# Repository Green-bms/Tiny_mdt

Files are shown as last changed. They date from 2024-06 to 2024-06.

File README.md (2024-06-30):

# Tiny_mdt
A useful tiny gadget! <br>  
Youtube video: https://www.youtube.com/embed/fY5Y1o6QoCc?si=GF92eTSO-mVCjJeZ <br> 
<br> 
Tiny mdt is a small electronic gadget that measures environmental data and shows it on a small 0.96" OLED display. 
The data is acquired and processed by an ATtiny85 microcontroller.<br> 
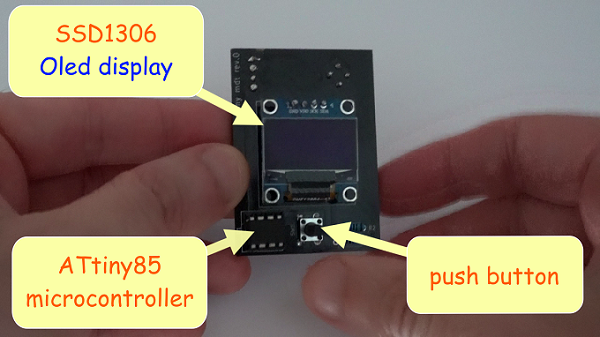
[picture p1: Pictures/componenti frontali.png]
) <br> 
The device is powered by a 3v CR2032 coin cell
the card only works when the power button is pressed and turns off when released.
So most of the time the device stays off, saving energy.
According to my calculations, with moderate use, the battery should last about 10-12 months.
I created the software with Arduino IDE. The big challenge was to find the lightest libraries to fit in the limited memory of the ATtiny85.
The project is available in 2 versions, with the same PCB (only the sensors to be used and the software to be loaded into the microcontroller change) <br>
## Type 1: htt
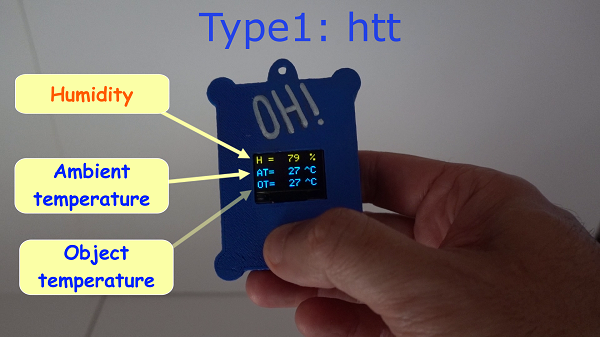
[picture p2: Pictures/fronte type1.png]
) <br> 
This variant uses the HTU21D sensor which measures humidity and ambient temperature.
Furthermore, the temperature of an object is also detected using the MLX90614 infrared thermometer. <br> 
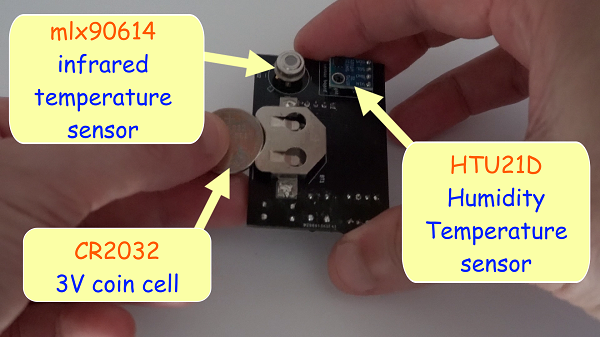
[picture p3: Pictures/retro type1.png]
) <br>
## Type 2: htp
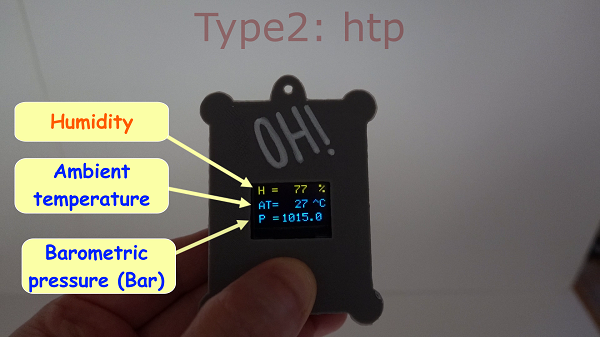
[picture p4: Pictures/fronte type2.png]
) <br> 
This is a small portable weather station in the palm of your hand!
The board uses the excellent BME280 sensor which measures humidity, temperature and barometric pressure.<br> 
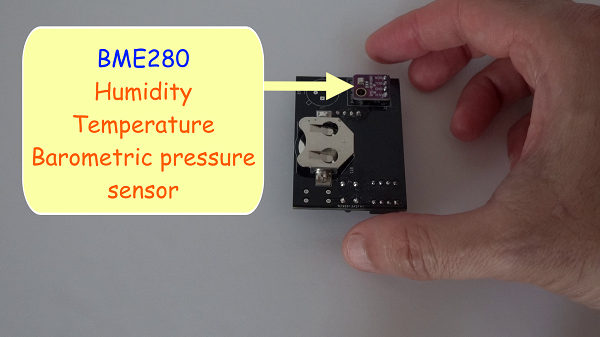
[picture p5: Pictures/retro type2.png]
) <br>
## Do it yourself
This project is completely open source and is very simple to create. <br>
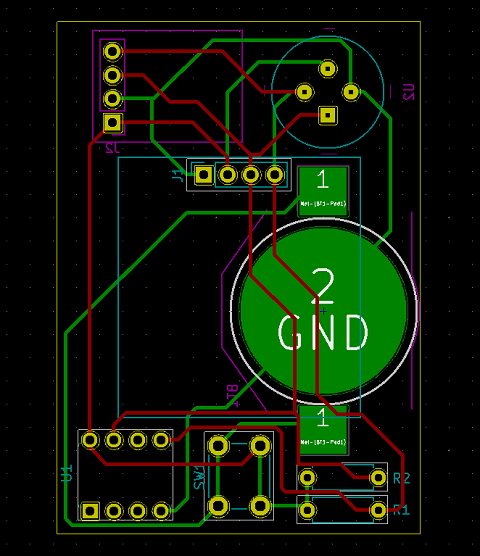
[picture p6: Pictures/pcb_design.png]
) <br>
I deliberately used tht components to facilitate soldering.<br>
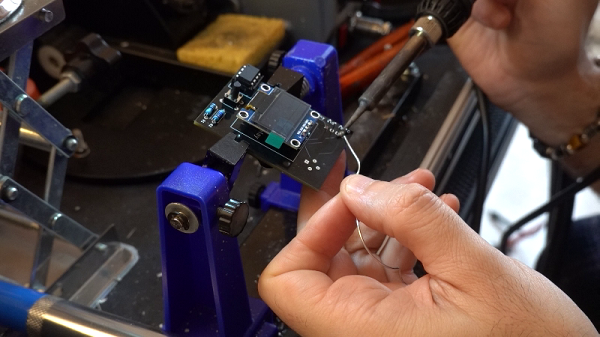
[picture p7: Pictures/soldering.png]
) <br>
The ATtiny85 microcontroller is socket mounted, so it can be easily removed and programmed using the maker's favorite programmer.
For example, I used the "Wemos as ISP" programmer that you find here: https://github.com/Green-bms/Wemos-as-ISP <br>
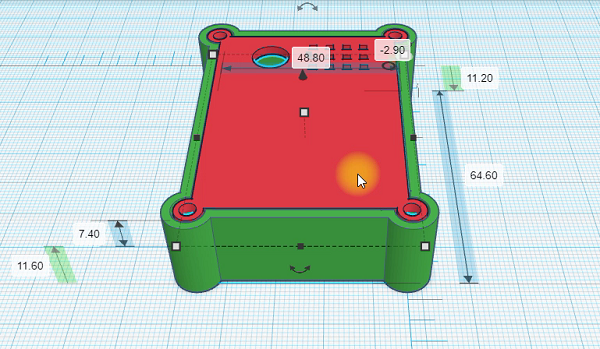
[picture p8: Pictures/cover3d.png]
) <br>

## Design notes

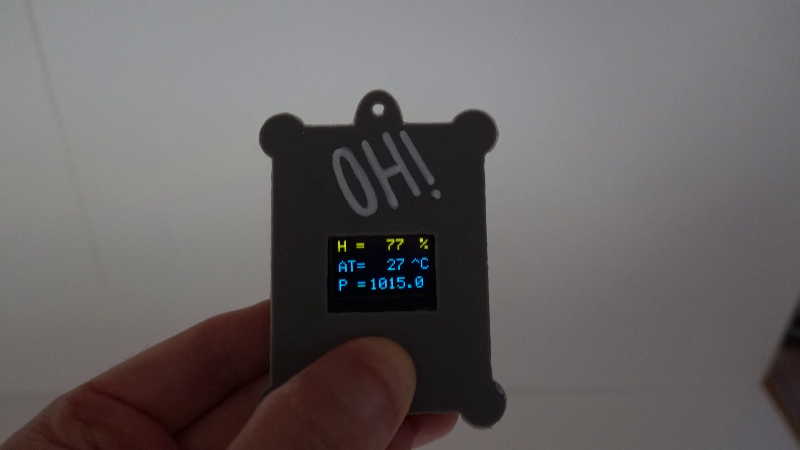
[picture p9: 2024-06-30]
Pictures/Istantanea.png

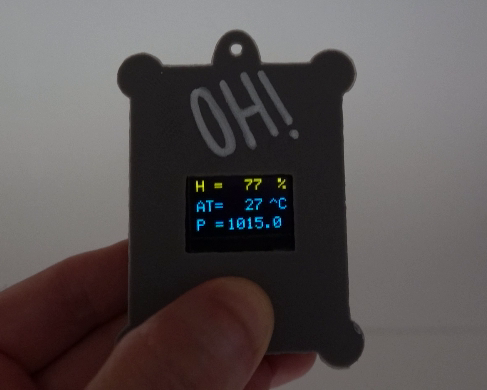
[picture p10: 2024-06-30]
Pictures/copertina.png

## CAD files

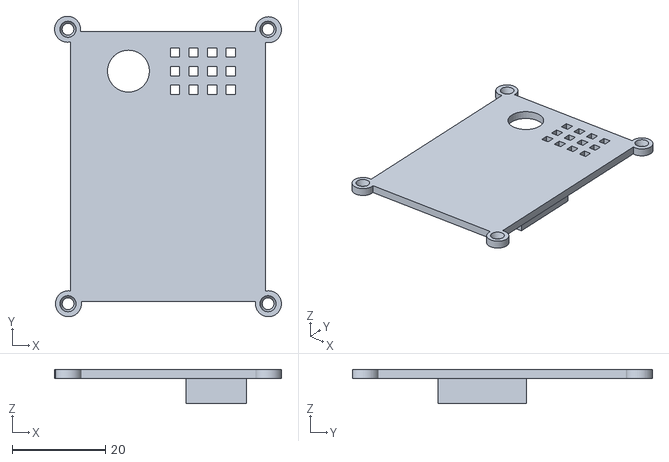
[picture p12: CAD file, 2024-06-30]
Cover 3D/Tiny_mdt_cover_htt_2.stl
48.8 x 64.6 x 7.40

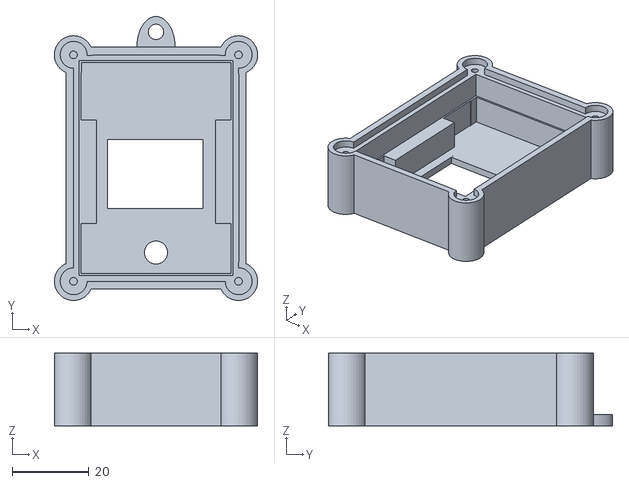
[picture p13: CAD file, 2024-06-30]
Cover 3D/Tiny_mdt_base_1.stl
53.0 x 74.0 x 19.0

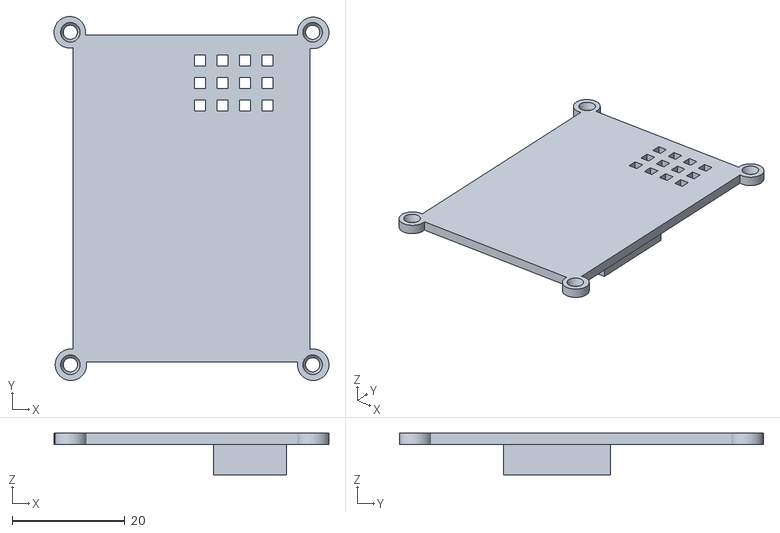
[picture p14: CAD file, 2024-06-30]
Cover 3D/Tiny_mdt_cover_htp_2.stl
48.8 x 64.6 x 7.40

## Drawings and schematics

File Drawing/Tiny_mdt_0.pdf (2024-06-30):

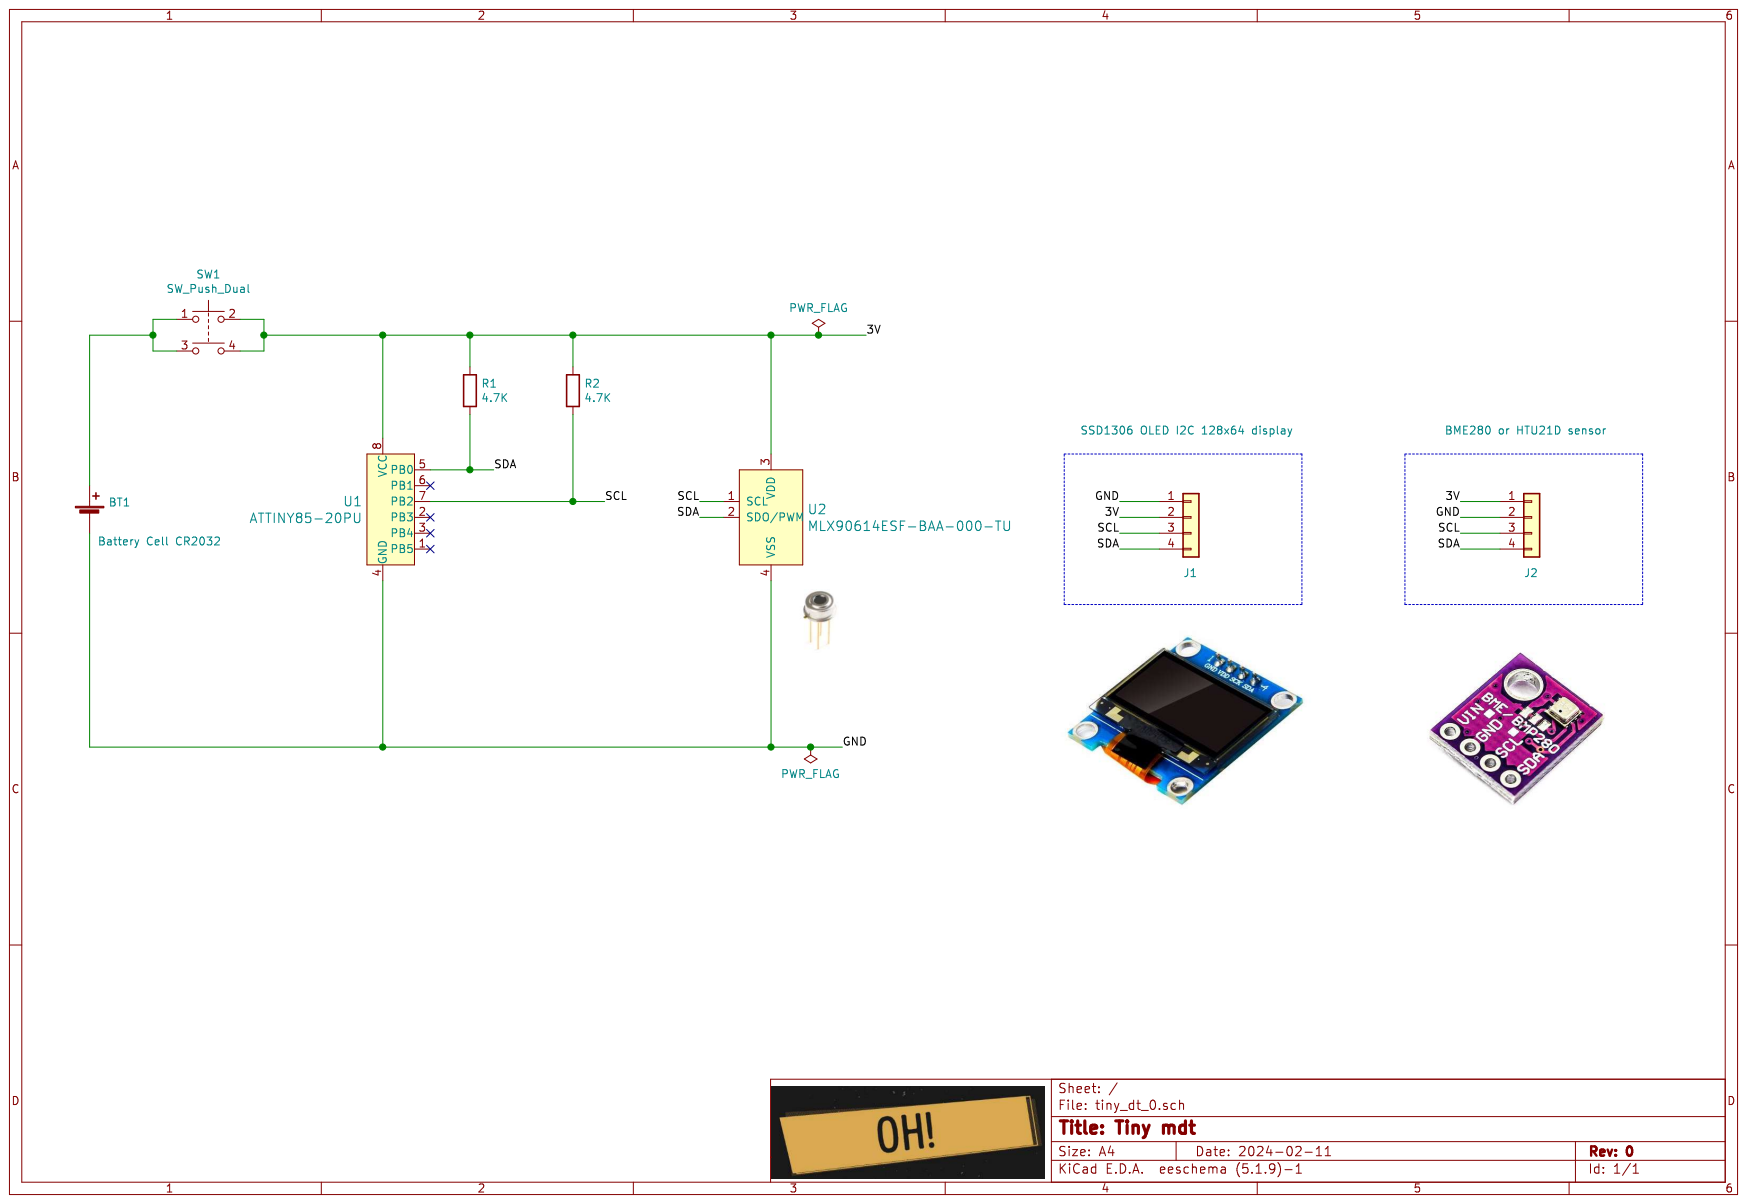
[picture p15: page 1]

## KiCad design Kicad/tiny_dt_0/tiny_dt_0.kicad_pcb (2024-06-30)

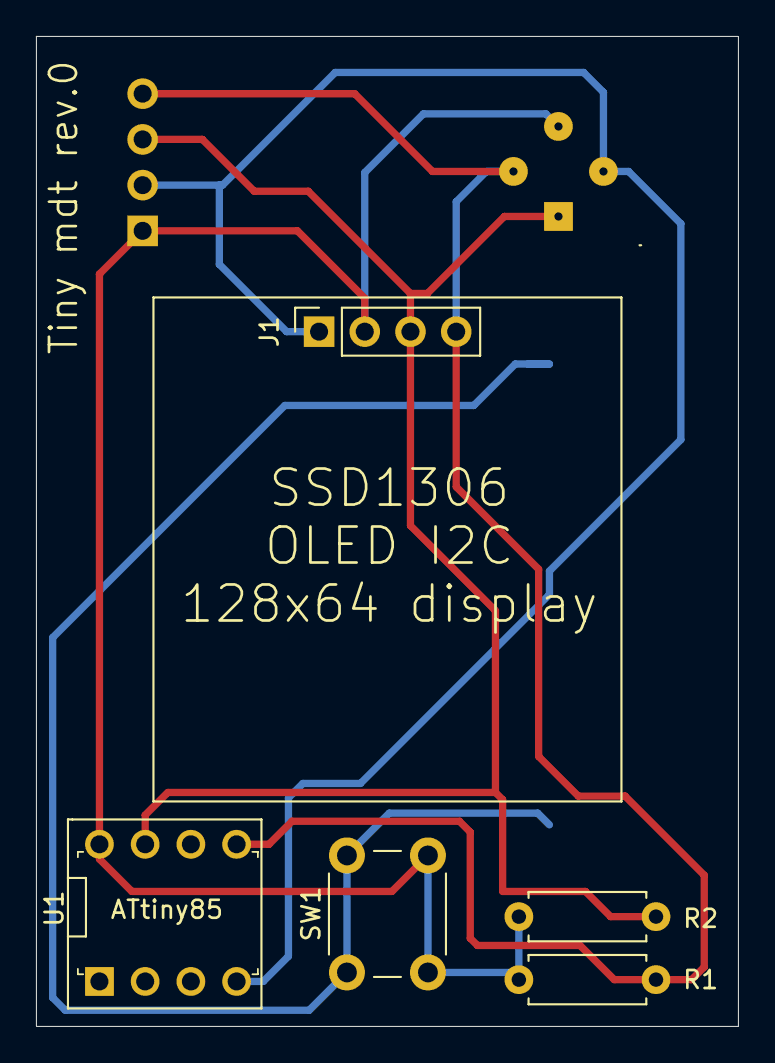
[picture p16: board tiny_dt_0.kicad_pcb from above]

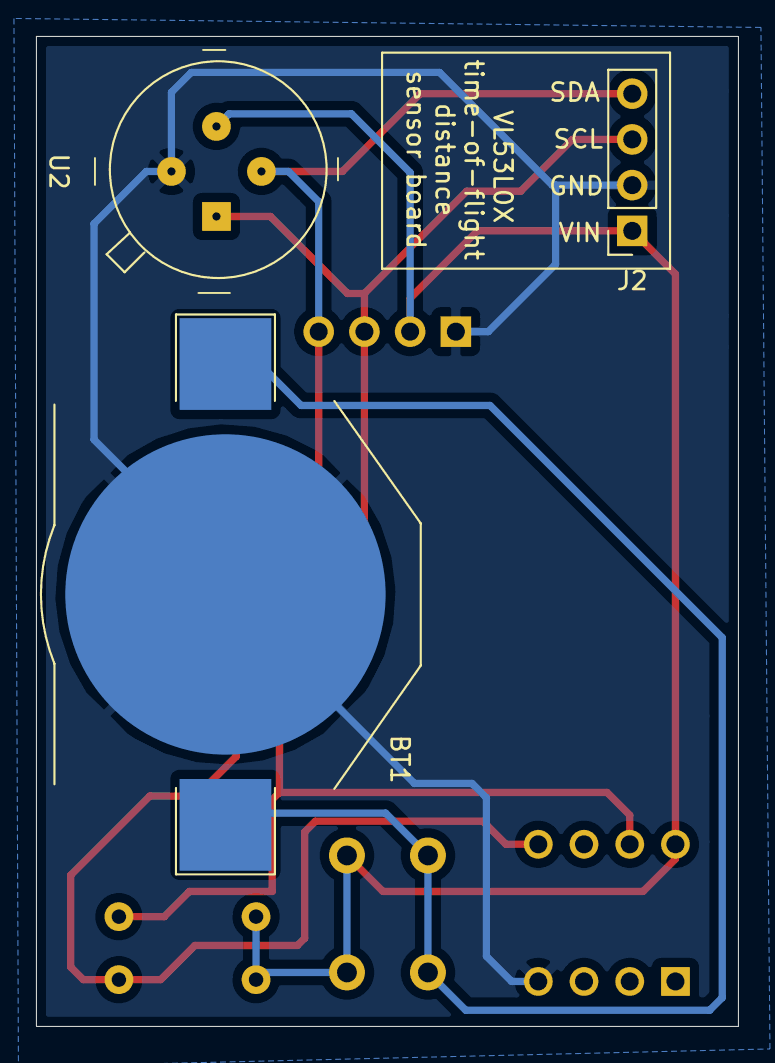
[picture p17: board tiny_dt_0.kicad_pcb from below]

Board: 2 copper layers, 39.0 x 55.0 mm, 8 parts (3 on the bottom side), 5 nets.

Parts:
BT1: Battery Cell CR2032; BatteryHolder_Keystone_3002_1x2032
J1: SSD1306 OLED I2C 128x64 display; PinSocket_1x04_P2.54mm_Vertical
J2: VL53L0X time-of-flight distance sensor board; PinSocket_1x04_P2.54mm_Vertical
R1, R2: 4.7K; R_Axial_DIN0207_L6.3mm_D2.5mm_P7.62mm_Horizontal
SW1: SW_Push_Dual; SW_PUSH_6mm
U1: ATTINY85-20PU; DIP-8_W7.62mm
U2: MLX90614ESF-BAA-000-TU; TO-39-4

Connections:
/3V: J1.2, J2.1, R1.1, R2.1, SW1.2, U1.8, U2.3
/GND: BT1.2, J1.1, J2.2, U1.4, U2.4
/SCL: J1.3, J2.3, R2.2, U1.7, U2.1
/SDA: J1.4, J2.4, R1.2, U1.5, U2.2
unnamed: BT1.1, SW1.1

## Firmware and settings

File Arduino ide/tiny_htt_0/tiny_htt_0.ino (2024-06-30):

/*
 tiny_htt

 Tiny portable gadget, which measures:
 - humidity and ambient temperature by HTU21D sensor
 - object temperature by MLX90614 sensor
 
 The measured data is shown on a 0.96 inch OLED display.
 The controller used is ATtiny85.
  
 Versions:

  - Ver. 0.00 date 27/06/2024 created by Sergio Ghirardelli (first release)

*/



#include <TinyWireM.h>
#include <Adafruit_MiniMLX90614.h>

#include <Wire.h>
#include "SparkFunHTU21D.h"


#include <Tiny4kOLED.h>



Adafruit_MiniMLX90614 mlx = Adafruit_MiniMLX90614();

HTU21D htu21d_sensor;






void setup() {
  mlx.begin();
  Wire.begin();
  delay(100);
  oled.begin(128, 64, sizeof(tiny4koled_init_128x64br), tiny4koled_init_128x64br);
  oled.clear();
  oled.on();
  oled.setFontX2(FONT6X8);
  oled.setContrast(1);
  oled.setCursor(0, 0);
  oled.print("H =      %");
  oled.setCursor(0, 3);
  oled.print("AT=     ^C");
  oled.setCursor(0, 6);
  oled.print("OT=     ^C");
  htu21d_sensor.begin();
  }
  


void loop() {

   float hum = htu21d_sensor.readHumidity();
   float t_amb = htu21d_sensor.readTemperature();
   float t_obj = mlx.readObjectTempC();
   
                      oled.setCursor(40, 0);
                      if ((hum > 100)||(hum < 0)) {oled.print("####");}
                         
                         else if (hum > 99) {
                          oled.print(" ");
                          oled.print(hum,0);
                          } 
                         else if (hum > 9) {
                          oled.print("  ");
                          oled.print(hum,0);
                          } 
                         else {
                          oled.print("   ");
                         oled.print(hum,0);
                          }
                    oled.setCursor(40, 3);
                      if ((t_amb > 125)||(hum < -40)) {oled.print("####");}
                      
                          else if ((t_amb > 99)||(t_amb < -9)) {
                          oled.print(" ");
                          oled.print(t_amb,0);
                          } 
                         else if ((t_amb > 9)||(t_amb < 0)) {
                          oled.print("  ");
                          oled.print(t_amb,0);
                          } 
                         else if (t_amb >= 0) {
                          oled.print("   ");
                          oled.print(t_amb,0);
                          }
                    oled.setCursor(40, 6);
                    if ((t_obj < -99)) {oled.print(t_obj,0);}
                          else if ((t_obj > 99)||(t_obj < -9)) {
                          oled.print(" ");
                          oled.print(t_obj,0);
                          } 
                         else if ((t_obj > 9)||(t_obj < 0)) {
                          oled.print("  ");
                          oled.print(t_obj,0);
                          } 
                         else if (t_obj >= 0) {
                          oled.print("   ");
                          oled.print(t_obj,0);
                          } 

                 
               
}
